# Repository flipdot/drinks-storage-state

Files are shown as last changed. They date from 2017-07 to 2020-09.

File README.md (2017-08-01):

# Drinks Storage State



This repo contains the design files (not yet) and firmware for the hardware, which measures the state of our beverage storage site.

## Concept

Our beverage storage site consists of multiple stacks of crates, where each stack can only contain one type of bottles which are either all full or all empty.

Each of the stacks is standing on a special scale, which monitors how many crates are on the stack.
Those special scales contain ESP8266 and send their state to a central server. The data is processed at server site and forwarded to a graphana server for visualisation.

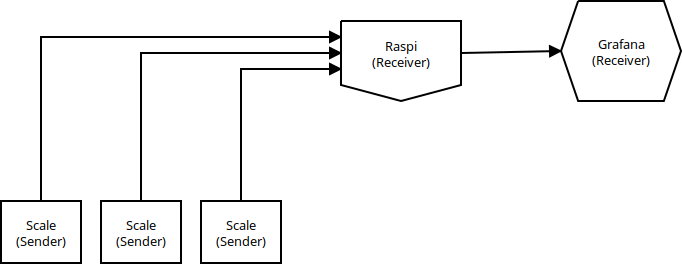
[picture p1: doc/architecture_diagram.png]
a diagram showing the overall architecture of the monitoring system


## Hardware

The Hardware is based on a board with 4 load cells attached to it according to the schematic of this [Load Sensor Combinator](https://www.sparkfun.com/products/13878):

| JP1_UL  | | Upper Left |
| --- | --- | --- |
| C | RED | E- |
| + | WHT | JP2_UR_WHT |
| - | BLK | JP3_LL_BLK |

| JP2_UR  | | Upper Right |
| --- | --- | --- |
| C | RED | A- |
| - | BLK | JP4_LR_BLK  |

| JP3_LL  | | Lower Left |
| --- | --- | --- |
| C | RED | A+ |
| + | WHT | JP4_LR_WHT |

| JP4_LR  | | Lower Right |
| --- | --- | --- |
| C | RED | E+ |

The signals of the load cells are amplified and digitalized by an HX711 load cell amplifier which is connected to an ESP8266 Board.

Currently the HX711 is hooked up to pins 12 & 14 (clock & data) of the ESP.

## Software

The software is written with the Arduino framework and build using [platformio](http://platformio.org/). To build the firmware and upload it to the ESP simply install platfomio and run `platformio run -t upload`.

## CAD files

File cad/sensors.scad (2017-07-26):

$fn=100;
include <rounded_square.scad>;


h_outer = 34;
w_outer = 34;
steg = 3;
h_inner = h_outer-(steg*2);
w_inner = w_outer-(steg*2);
rad_out = 9;
rad_in = 5;


//beer
dist_x = 420;
dist_y = 320;

// mate
//dist_x = 320;
//dist_y = 260;

dist_edge = 40;


module sensor_pad(){
  difference(){
    rounded_square([h_outer,w_outer],
        [rad_out, rad_out, rad_out, rad_out],
        center=true);
    translate([0, 2]){
      rounded_square([h_inner,w_inner-4],
          [rad_in, rad_in, rad_in, rad_in],
          center=true);   
    }
  }
}

difference(){
  square([dist_x, dist_y]);
  pad_dist_x = dist_x - dist_edge*2;
  pad_dist_y = dist_y - dist_edge*2;
  translate([dist_edge, dist_edge]){
    for (i=[0:1]){
      for(j=[0:1]){
        translate([pad_dist_x*i, pad_dist_y*j]){
          sensor_pad(); 
        }
      }
    }
  }
}

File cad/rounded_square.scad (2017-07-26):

// helper module for drawing rectangles with rounded borders
//
// (c) 2013 Felipe C. da S. Sanches <fsanches@metamaquina.com.br>
// Lincensed under the terms of the GNU General Public License
// version 3 (or later).

module rounded_square(dim, corners=[10,10,10,10], center=false){
  w=dim[0];
  h=dim[1];

  if (center){
    translate([-w/2, -h/2])
    rounded_square_(dim, corners=corners);
  }else{
    rounded_square_(dim, corners=corners);
  }
}

module rounded_square_(dim, corners, center=false){
  w=dim[0];
  h=dim[1];
  render(){
    difference(){
      square([w,h]);

      if (corners[0])
        square([corners[0], corners[0]]);

      if (corners[1])
        translate([w-corners[1],0])
        square([corners[1], corners[1]]);

      if (corners[2])
        translate([0,h-corners[2]])
        square([corners[2], corners[2]]);

      if (corners[3])
        translate([w-corners[3], h-corners[3]])
        square([corners[3], corners[3]]);
    }

    if (corners[0])
      translate([corners[0], corners[0]])
      intersection(){
        circle(r=corners[0]);
        translate([-corners[0], -corners[0]])
        square([corners[0], corners[0]]);
      }

    if (corners[1])
      translate([w-corners[1], corners[1]])
      intersection(){
        circle(r=corners[1]);
        translate([0, -corners[1]])
        square([corners[1], corners[1]]);
      }

    if (corners[2])
      translate([corners[2], h-corners[2]])
      intersection(){
        circle(r=corners[2]);
        translate([-corners[2], 0])
        square([corners[2], corners[2]]);
      }

    if (corners[3])
      translate([w-corners[3], h-corners[3]])
      intersection(){
        circle(r=corners[3]);
        square([corners[3], corners[3]]);
      }
  }
}

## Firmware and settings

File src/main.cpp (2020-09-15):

#include <algorithm>
#include <vector>

#include <cstring>

#include <Arduino.h>
#include <ArduinoJson.h>
#include <ESP8266WiFi.h>
#include <HX711.h>
#include <PubSubClient.h>

#include "config.hpp"

using namespace std;

const uint32_t CHIP_ID = ESP.getChipId();
const uint8_t FAIL_LIMIT_MQTT = 20;

WiFiClient wifi_client;
PubSubClient mqtt_client(MQTT_HOST, 1883, wifi_client);

HX711* scale;
vector<long> last_measurements;
uint8_t fails_mqtt = 0;
uint32_t packets_sent = 0;

long compute_median(vector<long> values) {
    nth_element(values.begin(), values.begin() + (M_SAMPLES / 2), values.end());
    return values[M_SAMPLES / 2];
}

long send_value(long value) {
    // Format JSON
    DynamicJsonBuffer json_buffer;
    JsonObject& root = json_buffer.createObject();
    root["esp_id"] = CHIP_ID;
    root["scale_value"] = value;
    root["packets_sent"] = String(packets_sent);
    packets_sent++;
    String json_string;
    root.printTo(json_string);

    // Send MQTT message
    Serial.printf("\nPublishing to MQTT broker (%s): %s... ", MQTT_HOST, json_string.c_str());
    if (mqtt_client.publish(MQTT_TOPIC, json_string.c_str())) {
        Serial.printf("success.");
    } else {
        Serial.printf("FAILED!");
        fails_mqtt++;
    }
}

int wifi_connect() {
    WiFi.softAPdisconnect(true);
    Serial.println("Disabled SoftAP mode.");
    Serial.print("Connecting to WiFi.");
    WiFi.begin(SSID, PASSWORD);

    int fails_wifi = 0;
    while (WiFi.status() != WL_CONNECTED) {
        delay(500);
        Serial.print(".");
        fails_wifi++;
        if (fails_wifi > 60) {
            Serial.println("\nConnection timed out.");
            Serial.println("Restarting...\n");
            ESP.restart();
            return 0;
        }
    }
    return 1;
}

void setup() {
    delay(1000);

    last_measurements.reserve(M_SAMPLES);

    // Initialize serial
    Serial.begin(115200);
    Serial.println("\n");

    // Initialize HX711 ADC module
    Serial.println("Initializing HX711 ADC module...");
    scale = new HX711(DATA_PIN, CLOCK_PIN);

    // Initialize WiFi connection
    while (!wifi_connect()) {
        continue;
    }

    Serial.printf("\nConnected to: %s with IP address %s\n",
            SSID,
            WiFi.localIP().toString().c_str());

    char client_id[9];
    snprintf(client_id, 8, "%X", CHIP_ID);

    if (!mqtt_client.connect(client_id)) {
        Serial.println("Problems connecting to MQTT broker. Restarting...\n");
        ESP.restart();
    }

    Serial.println("Connected to MQTT broker.");
    Serial.println("Setup complete!\n");
}

void loop() {
    long measurement = scale->read();
    last_measurements.push_back(measurement);
    if (last_measurements.size() > M_SAMPLES) {
        // Compute median
        long measurement_median = compute_median(last_measurements);

        // Send value
        send_value(measurement_median);
        last_measurements.clear();
        if (fails_mqtt > FAIL_LIMIT_MQTT) {
            Serial.println("\nProblems with broker. Restarting...\n");
            ESP.restart();
        }
    }
}

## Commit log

2017-07-26 add CAD files
    [rounded_square.scad, sensors.scad]
2017-07-30 Replace HTTP by MQTT (only compile-tested, sorry)
    [main.cpp]
2020-09-15 Pin libary versions
